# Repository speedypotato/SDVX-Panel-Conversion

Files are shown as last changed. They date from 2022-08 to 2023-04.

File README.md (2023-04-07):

# SDVX-Panel-Conversion
Turn an arcade Sound Voltex panel into a controller.

Requires a 1x2ft laser cutter, a 3d printer, and an assortment of m3 and m4 nuts and bolts.  And rubber feet.  And some more stuff.

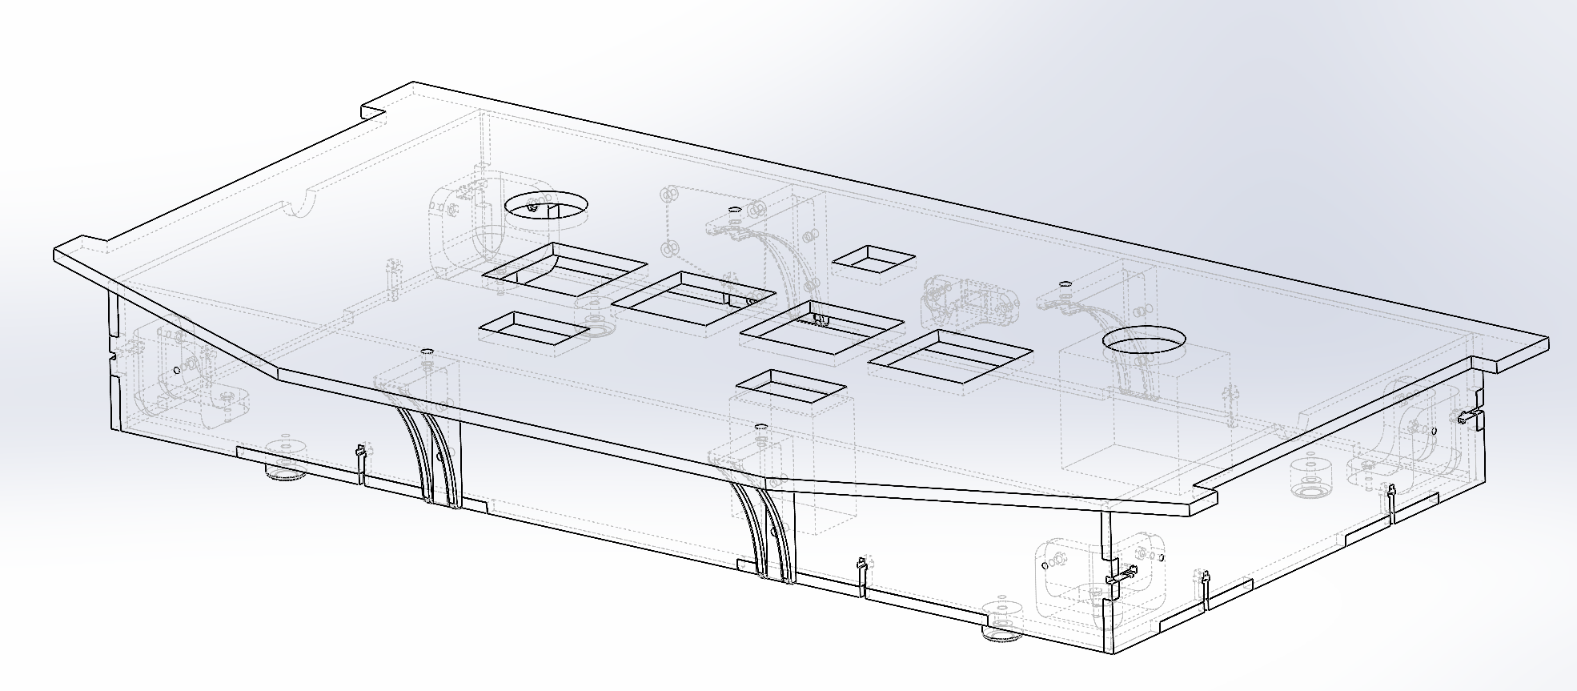
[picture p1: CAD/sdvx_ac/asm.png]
Wireframe


issues:  
- arduino holes didn't exactly line up, i just screwed in 2 screws diagonally and called it a day
- the m3x20 screws may fall out.  the corner brackets seem to do a good enough job,  can super glue m3 washers to make the m3x20 screws stay.

Note: PCB folder contains a side led rgb pcb which i was originally going to use, but the pcba turned out too expensive so I have went with the 3d printed mount instead

requires:  
- 2 1/4" 1x2ft plywood panels - mine came out to be 5.5mm..so ymmv.  Laser cut with box_dxf, units are mm
- 3d printed parts: 4 corner_bracket, 2 back_mount, 2 front_mount, 1 usb_mount, 1 arduino_leonaro_mount, 1 led_3dp, and 1 led_3dp but print mirrored
- 3m mounting tape for arduino and led sides
- m3x6 arduino
- m3x16 corner brackets
- m4x12 panel to box mount
- m3 nuts
- m4 nuts
- m3 washers
- m4 washers
- m4xsomething nuts to mount arcade panel to box
- m4 screwable rubber feet.  I got these https://www.mcmaster.com/8884T21
- top screws.  got them from a friend, they look like m4 low/slim profile of some sort.  m4x16 or something.
- ws2812b strip - i got 1m of 144leds/m because why not.

Assembly:  
- Note: I recommend doing a washer wherever a screw head touches wood or a 3d print.
- screw together box with corner pieces
- glue usb c - micro b extender into the usb holder
- screw in usb holder
- screw in front and back 3d printed mounts to box, don't forget to add nuts to all 3 points
- screw in panel
- mount arduino to plastic holder, apply 3m tape to holder.
- create wiring harness or just use dupont breadboard extenders and plug it directly into the connector using the wiring guide.  I recommend grouping all the - and COM to ground, except L/R Pot -, which get their own dedicated wire to ground
- don't forget to wire up ws2812b, needs to tap into 5v and gnd of the harness and each side has its own dedicated data line.  Cut to length, for mine i did 31 leds per side.
- assuming you've wired up arduino, plug in the micro usb adapter, peel off other side of 3m tape and mount it inside.  for me, i did it in the top left corner(looking at the top of the panel)
- string ws2812b strips through the half circle gaps to the outside of the box.
- apply mounting tape to edges of led_3dp part, then stick ws2812b strip to the mount.  Peel mounting tape and apply to panel.  Repeat for other side.
- mount feet to the bottom panel
- screw in the bottom panel

Setup https://github.com/veroxzik/arduino-konami-spoof (C:\Program Files (x86)\Arduino\hardware for me) and flash SkogaVoltex.  Might need to add arduino joystick library(just google it and import the zip).  Fastled, bounce2, and responsiveanalogread libraries can be installed through tools -> manage libraries.

This work is licensed under a Creative Commons Attribution-NonCommercial-ShareAlike 4.0 International License.

My build, including extras:  
dupont	7.3  
ws2812b	8.26  
panel	63.51  
shipping	69.5  
arduino	14.99  
usb c to micro b	1.915  
wood	8.47  
screws	15.89  
feet	3.18  
3d prints	5  
jst	0  
wire	1  
torque limiter	44  
yuan leds	11.01  
usb c cable	1  
knobs	19.98 
3m tape 5 

Total: 280.005

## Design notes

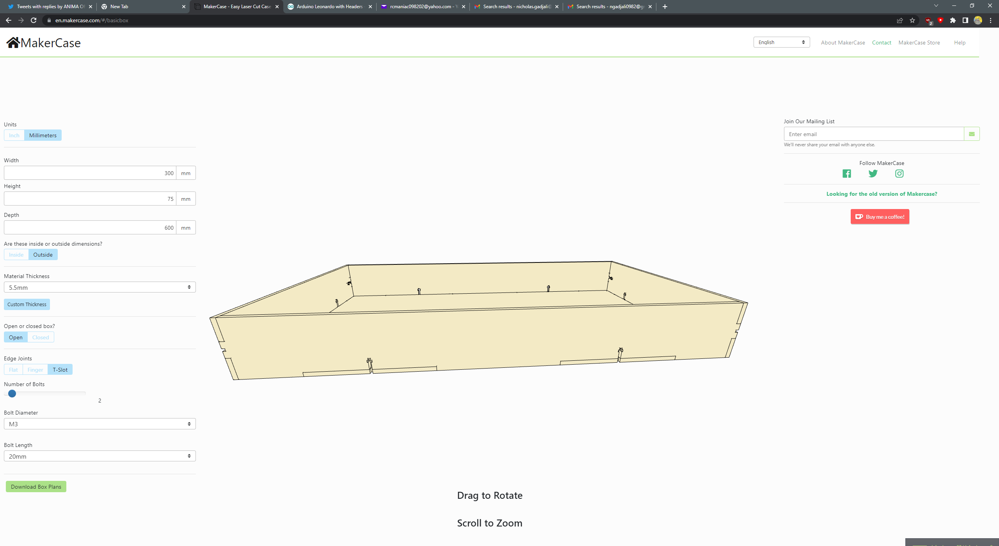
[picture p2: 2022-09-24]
CAD/sdvx_ac/box/box.png

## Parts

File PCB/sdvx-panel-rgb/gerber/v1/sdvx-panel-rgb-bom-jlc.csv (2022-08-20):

Comment | Designator | Footprint | LCSC
100nF | C1,C2,C3,C4,C5,C6,C7,C8 | Capacitor_SMD:C_0603_1608Metric_Pad1.08x0.95mm_HandSolder | C1525
s3b-xh-sm4-tb | J1,J2 | user:S3B-XH-SM4-TB | C161860
WS2812B-4020 | LED1,LED2,LED3,LED4,LED5,LED6,LED7,LED8 | agg:WS2812B-4020 | C965557

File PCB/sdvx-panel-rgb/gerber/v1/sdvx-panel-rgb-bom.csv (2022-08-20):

Source: | D:\KiCad\sdvx-panel-rgb\sdvx-panel-rgb.kicad_sch
Date: | 8/19/2022 23:46
Tool: | Eeschema (6.0.2)
Generator: | C:\Program Files\KiCad\6.0\bin\scripting\plugins/bom_csv_grouped_by_value.py
Component Count: | 20
Individual Components:
Item | Qty | Reference(s) | Value | LibPart | Footprint | Datasheet | LCSC
 |  | C1 | 100nF | Device:C_Small | Capacitor_SMD:C_0603_1608Metric_Pad1.08x0.95mm_HandSolder | ~ | C1525
 |  | C2 | 100nF | Device:C_Small | Capacitor_SMD:C_0603_1608Metric_Pad1.08x0.95mm_HandSolder | ~ | C1525
 |  | C3 | 100nF | Device:C_Small | Capacitor_SMD:C_0603_1608Metric_Pad1.08x0.95mm_HandSolder | ~ | C1525
 |  | C4 | 100nF | Device:C_Small | Capacitor_SMD:C_0603_1608Metric_Pad1.08x0.95mm_HandSolder | ~ | C1525
 |  | C5 | 100nF | Device:C_Small | Capacitor_SMD:C_0603_1608Metric_Pad1.08x0.95mm_HandSolder | ~ | C1525
 |  | C6 | 100nF | Device:C_Small | Capacitor_SMD:C_0603_1608Metric_Pad1.08x0.95mm_HandSolder | ~ | C1525
 |  | C7 | 100nF | Device:C_Small | Capacitor_SMD:C_0603_1608Metric_Pad1.08x0.95mm_HandSolder | ~ | C1525
 |  | C8 | 100nF | Device:C_Small | Capacitor_SMD:C_0603_1608Metric_Pad1.08x0.95mm_HandSolder | ~ | C1525
 |  | J1 | s3b-xh-sm4-tb | agg-kicad:CONN_01x03 | user:S3B-XH-SM4-TB |  | C161860
 |  | J2 | s3b-xh-sm4-tb | agg-kicad:CONN_01x03 | user:S3B-XH-SM4-TB |  | C161860
 |  | LED1 | WS2812B-4020 | agg-kicad:WS2812B-4020 | agg:WS2812B-4020 | https://datasheet.lcsc.com/szlcsc/2012110135_Worldsemi-WS2812B-4020_C965557.pdf | C965557
 |  | LED2 | WS2812B-4020 | agg-kicad:WS2812B-4020 | agg:WS2812B-4020 | https://datasheet.lcsc.com/szlcsc/2012110135_Worldsemi-WS2812B-4020_C965557.pdf | C965557
 |  | LED3 | WS2812B-4020 | agg-kicad:WS2812B-4020 | agg:WS2812B-4020 | https://datasheet.lcsc.com/szlcsc/2012110135_Worldsemi-WS2812B-4020_C965557.pdf | C965557
 |  | LED4 | WS2812B-4020 | agg-kicad:WS2812B-4020 | agg:WS2812B-4020 | https://datasheet.lcsc.com/szlcsc/2012110135_Worldsemi-WS2812B-4020_C965557.pdf | C965557
 |  | LED5 | WS2812B-4020 | agg-kicad:WS2812B-4020 | agg:WS2812B-4020 | https://datasheet.lcsc.com/szlcsc/2012110135_Worldsemi-WS2812B-4020_C965557.pdf | C965557
 |  | LED6 | WS2812B-4020 | agg-kicad:WS2812B-4020 | agg:WS2812B-4020 | https://datasheet.lcsc.com/szlcsc/2012110135_Worldsemi-WS2812B-4020_C965557.pdf | C965557
 |  | LED7 | WS2812B-4020 | agg-kicad:WS2812B-4020 | agg:WS2812B-4020 | https://datasheet.lcsc.com/szlcsc/2012110135_Worldsemi-WS2812B-4020_C965557.pdf | C965557
 |  | LED8 | WS2812B-4020 | agg-kicad:WS2812B-4020 | agg:WS2812B-4020 | https://datasheet.lcsc.com/szlcsc/2012110135_Worldsemi-WS2812B-4020_C965557.pdf | C965557
Collated Components:
Item | Qty | Reference(s) | Value | LibPart | Footprint | Datasheet | LCSC
1 | 8 | C1, C2, C3, C4, C5, C6, C7, C8 | 100nF | Device:C_Small | Capacitor_SMD:C_0603_1608Metric_Pad1.08x0.95mm_HandSolder | ~ | C1525
2 | 2 | J1, J2 | s3b-xh-sm4-tb | agg-kicad:CONN_01x03 | user:S3B-XH-SM4-TB |  | C161860
3 | 8 | LED1, LED2, LED3, LED4, LED5, LED6, LED7, LED8 | WS2812B-4020 | agg-kicad:WS2812B-4020 | agg:WS2812B-4020 | https://datasheet.lcsc.com/szlcsc/2012110135_Worldsemi-WS2812B-4020_C965557.pdf | C965557

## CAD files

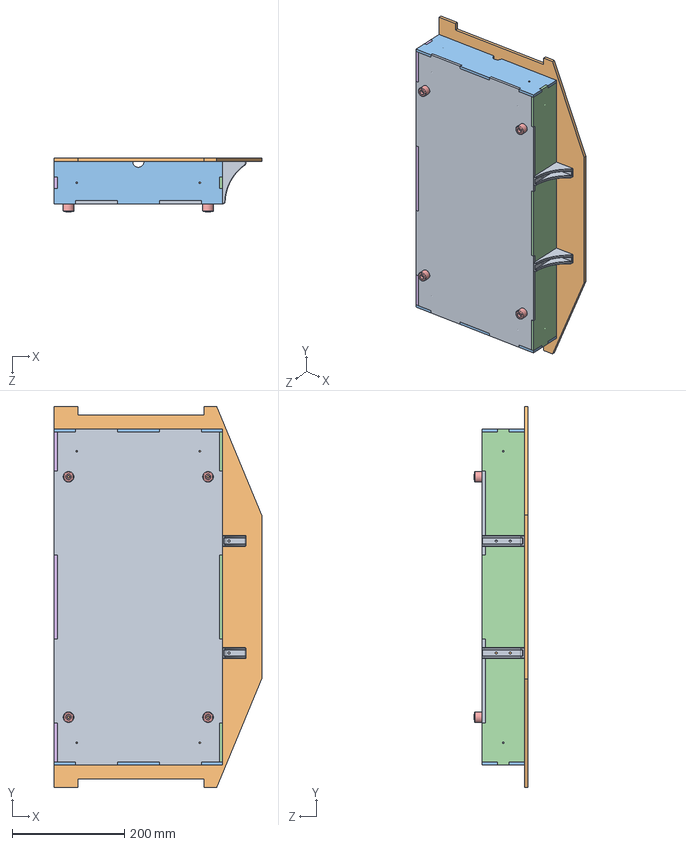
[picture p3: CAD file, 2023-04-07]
CAD/sdvx_ac/box/sdvx_ac.SLDASM
370.4 x 680.0 x 95.5 mm
bottom
panel
side x 2
front
8884T21_Heavy Duty Unthreaded Bumpers x 4
back
usb_mount
arduino_leonardo_mount
front_mount x 2
back_mount x 2
corner_bracket x 4

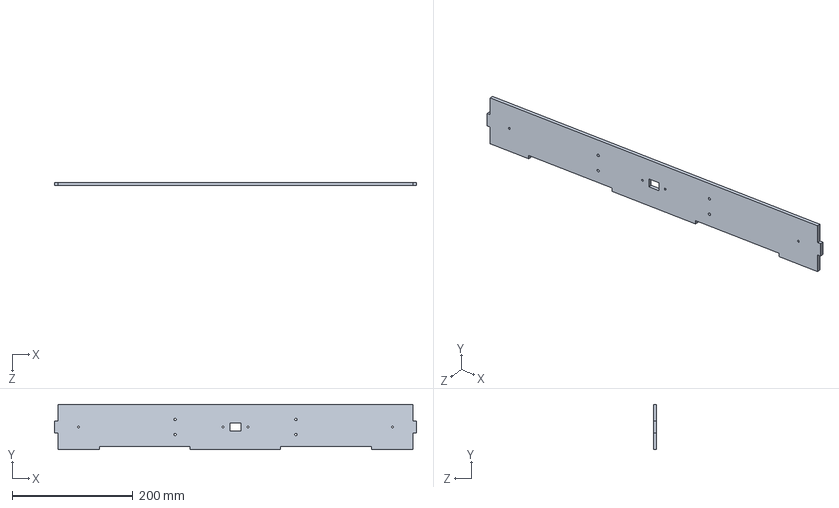
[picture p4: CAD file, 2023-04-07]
CAD/sdvx_ac/box/back.SLDPRT
600.0 x 75.0 x 5.50 mm

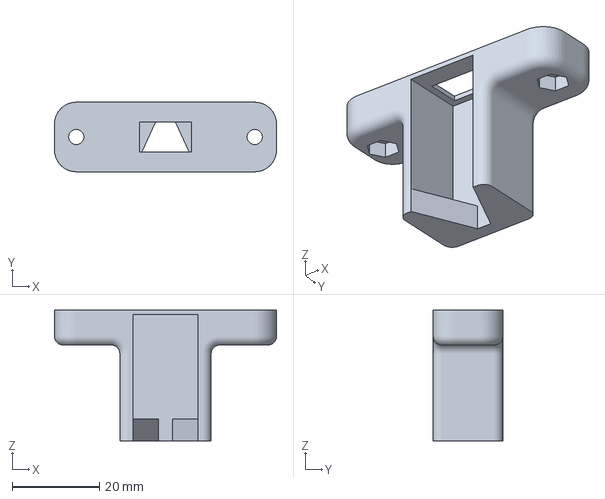
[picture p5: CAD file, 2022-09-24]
CAD/sdvx_ac/box/box_3mf/usb_mount.3MF
51.0 x 16.0 x 30.0 mm

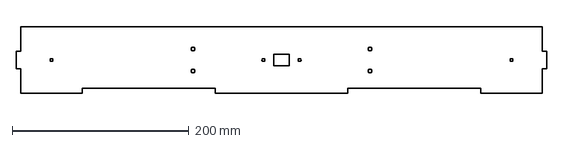
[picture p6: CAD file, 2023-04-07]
CAD/sdvx_ac/box/box_dxf/back.DXF
600.0 x 75.0 mm

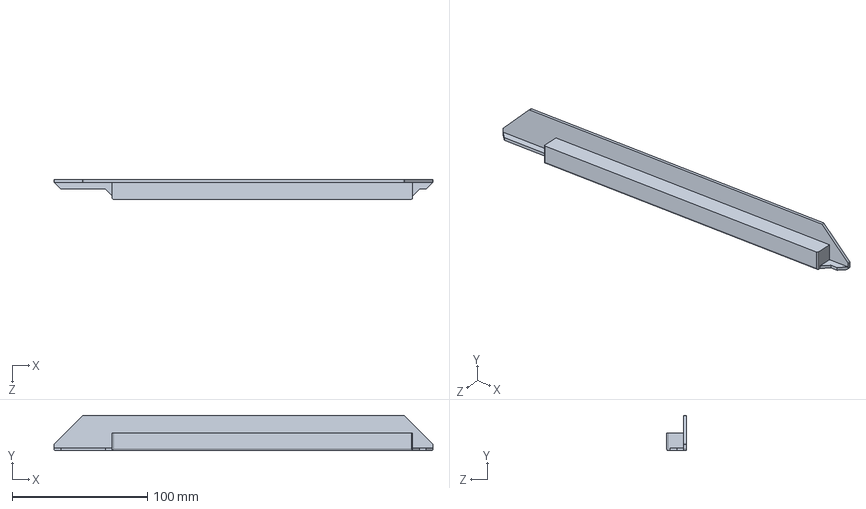
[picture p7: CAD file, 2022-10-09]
CAD/sdvx_ac/led_board_3dp/led_3dp.SLDPRT
280.0 x 26.0 x 14.5 mm

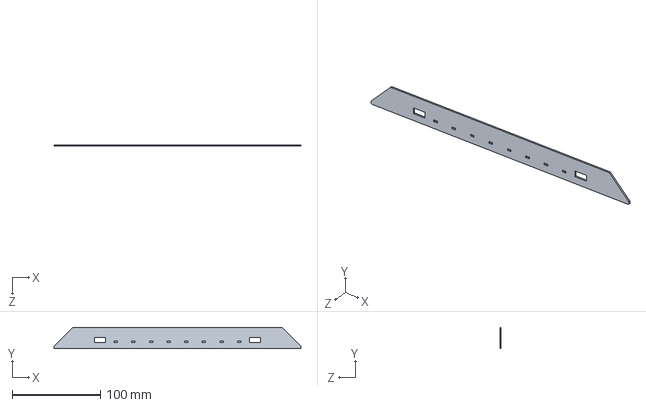
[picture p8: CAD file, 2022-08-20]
CAD/sdvx_ac/led_board_sym.SLDPRT
280.0 x 24.0 x 1.60 mm

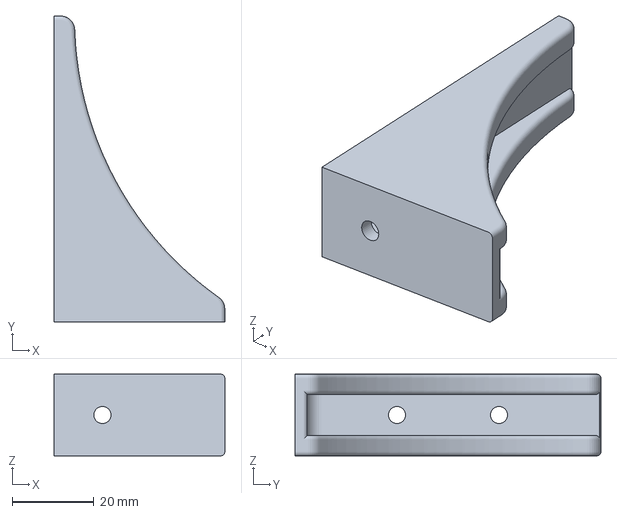
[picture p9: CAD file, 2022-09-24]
CAD/sdvx_ac/box/box_3mf/front_mount.3MF
41.8 x 75.0 x 20.0 mm

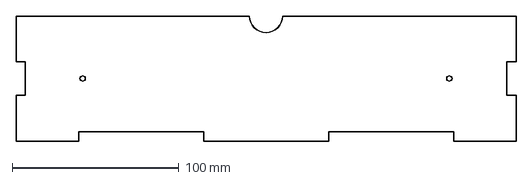
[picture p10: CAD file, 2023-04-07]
CAD/sdvx_ac/box/box_dxf/side.DXF
300.0 x 75.0 mm

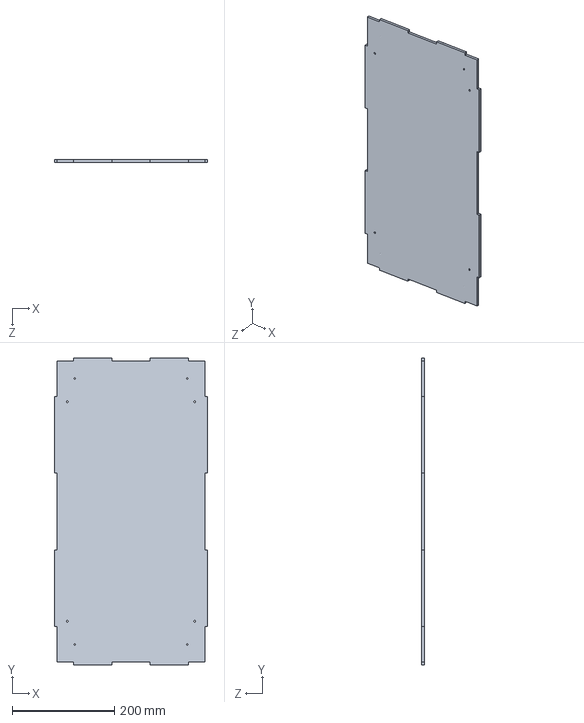
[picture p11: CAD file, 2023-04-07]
CAD/sdvx_ac/box/bottom.SLDPRT
300.0 x 600.0 x 5.50 mm

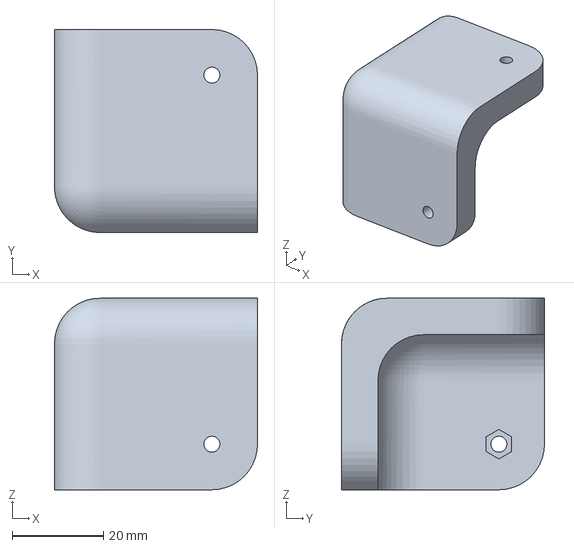
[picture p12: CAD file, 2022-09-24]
CAD/sdvx_ac/box/box_3mf/corner_bracket.3MF
44.5 x 44.5 x 42.0 mm

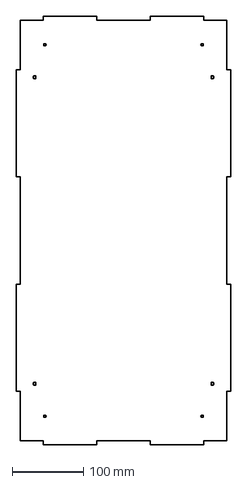
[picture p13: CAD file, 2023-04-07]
CAD/sdvx_ac/box/box_dxf/bottom.DXF
300.0 x 600.0 mm

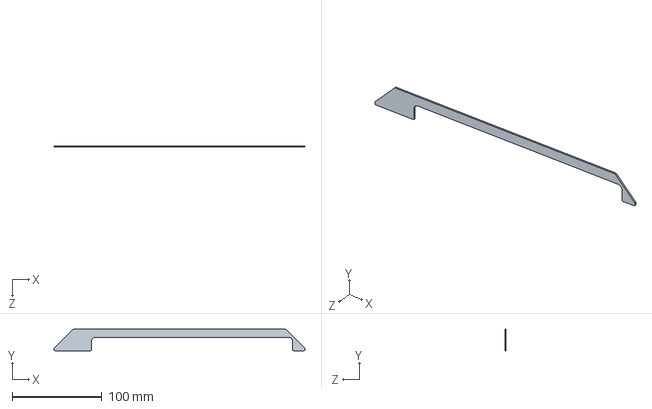
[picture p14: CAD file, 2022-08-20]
CAD/sdvx_ac/led_board.SLDPRT
280.0 x 24.0 x 1.60 mm

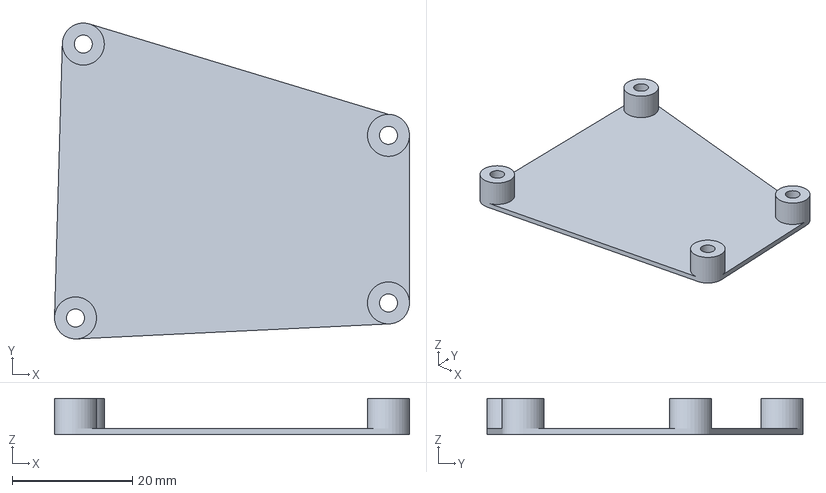
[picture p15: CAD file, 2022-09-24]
CAD/sdvx_ac/box/box_3mf/arduino_leonardo_mount.3MF
59.1 x 52.6 x 6.00 mm

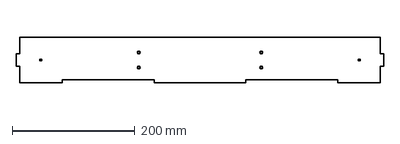
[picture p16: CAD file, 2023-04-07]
CAD/sdvx_ac/box/box_dxf/front.DXF
600.0 x 75.0 mm

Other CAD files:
CAD/sdvx_ac/box/front.SLDPRT
CAD/sdvx_ac/led_board_sym_cutout.SLDPRT
CAD/sdvx_ac/box/box_3mf/back_mount.3MF
CAD/sdvx_ac/box/side.SLDPRT
CAD/sdvx_ac/box/acrylic_panel.dxf
CAD/sdvx_ac/box/arduino_leonardo_mount.SLDPRT
CAD/sdvx_ac/box/back_mount.SLDPRT
CAD/sdvx_ac/box/box.dxf
CAD/sdvx_ac/box/corner_bracket.SLDPRT
CAD/sdvx_ac/box/front_mount.SLDPRT
CAD/sdvx_ac/box/mounting holes.SLDPRT
CAD/sdvx_ac/box/panel.SLDPRT
CAD/sdvx_ac/box/parts/8884T21_Heavy Duty Unthreaded Bumpers.SLDPRT
CAD/sdvx_ac/box/usb_mount.SLDPRT
CAD/sdvx_ac/led_board_3dp/led_3dp.3MF
CAD/sdvx_ac/led_board_sym.DXF
CAD/sdvx_ac/led_board_sym_cutout.DXF

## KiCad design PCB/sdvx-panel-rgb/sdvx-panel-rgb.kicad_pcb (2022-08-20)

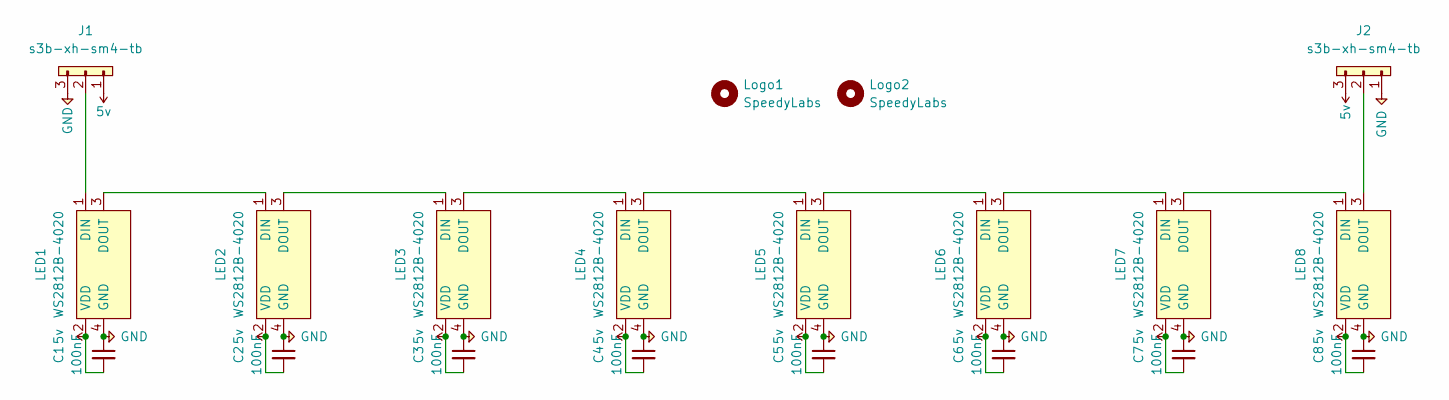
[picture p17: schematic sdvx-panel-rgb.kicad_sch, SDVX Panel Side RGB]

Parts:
C1, C2, C3, C4, C5, C6, C7, C8: 100nF; C_0603_1608Metric_Pad1.08x0.95mm_HandSolder; LCSC C1525
J1, J2: s3b-xh-sm4-tb; S3B-XH-SM4-TB; LCSC C161860
LED1, LED2, LED3, LED4, LED5, LED6, LED7, LED8: WS2812B-4020; LCSC C965557
Logo1, Logo2: SpeedyLabs; logo_small

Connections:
5v: C1.2, C2.2, C3.2, C4.2, C5.2, C6.2, C7.2, C8.2, J1.1, J2.3, LED1.2 (VDD), LED2.2 (VDD), LED3.2 (VDD), LED4.2 (VDD), LED5.2 (VDD), LED6.2 (VDD), LED7.2 (VDD), LED8.2 (VDD)
GND: C1.1, C2.1, C3.1, C4.1, C5.1, C6.1, C7.1, C8.1, J1.3, J2.1, LED1.4 (GND), LED2.4 (GND), LED3.4 (GND), LED4.4 (GND), LED5.4 (GND), LED6.4 (GND), LED7.4 (GND), LED8.4 (GND)
unnamed: J1.2, LED1.1 (DIN)
unnamed: LED1.3 (DOUT), LED2.1 (DIN)
unnamed: LED2.3 (DOUT), LED3.1 (DIN)
unnamed: LED3.3 (DOUT), LED4.1 (DIN)
unnamed: LED4.3 (DOUT), LED5.1 (DIN)
unnamed: LED5.3 (DOUT), LED6.1 (DIN)
unnamed: LED6.3 (DOUT), LED7.1 (DIN)
unnamed: LED7.3 (DOUT), LED8.1 (DIN)
unnamed: J2.2, LED8.3 (DOUT)

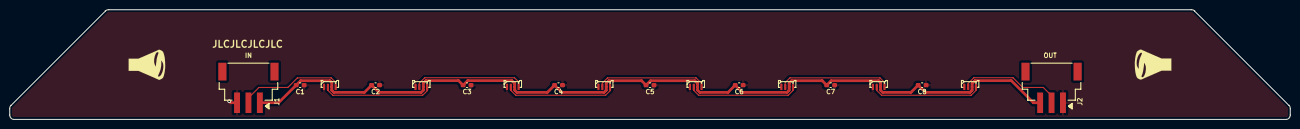
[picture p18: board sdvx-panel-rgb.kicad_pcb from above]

Board: 2 copper layers, 280.0 x 24.0 mm, 20 parts (0 on the bottom side), 11 nets.

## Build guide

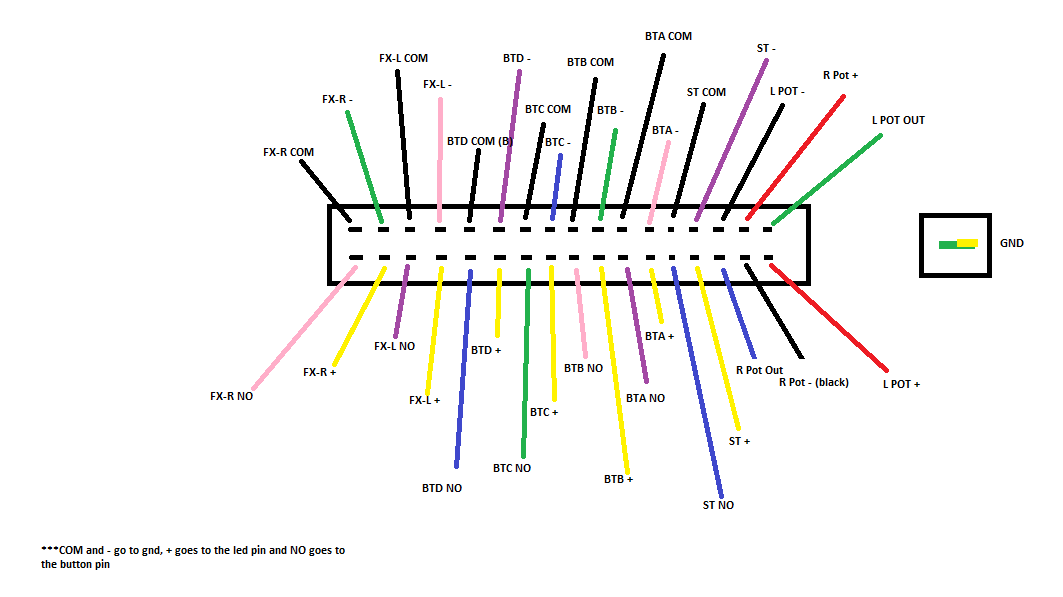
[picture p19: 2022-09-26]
SDVX_Wiring_Guide_Arcade_Panel.png

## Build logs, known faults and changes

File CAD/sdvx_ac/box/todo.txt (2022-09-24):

-box needs holes for mounting hole l brackets
-usb cutout/mount
-arduino mount

maybe rgb strip + 3d printed enclosure

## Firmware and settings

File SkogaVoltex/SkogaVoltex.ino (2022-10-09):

/**
 * Originally written by Skogaby
 * Modified by SpeedyPotato
 */

#define cbi(sfr, bit) (_SFR_BYTE(sfr) &= ~_BV(bit))
#define sbi(sfr, bit) (_SFR_BYTE(sfr) |= _BV(bit))

#include <Bounce2.h>
#include <FastLED.h>
#include <Joystick.h>
#include <ResponsiveAnalogRead.h>
#include "PluggableUSB.h"
#include "HID.h"

// Pin setup
#define ADC_MAX 1024
#define NUM_BUTTONS 9
#define NUM_KNOBS 2
#define NUM_LED_STRIPS 2
#define NUM_LEDS_PER_STRIP 31
#define LED_TYPE WS2812B
#define LED_ORDER GRB

// HID lighting setup
#define NUMBER_OF_SINGLE 7
#define NUMBER_OF_RGB 1

bool lightStates[NUMBER_OF_SINGLE] = { false };
unsigned long lightTimestamp = 0;

typedef struct {
  uint8_t brightness;
} SingleLED;

typedef struct {
  uint8_t r;
  uint8_t g;
  uint8_t b;
} RGBLed;

// Main output
Joystick_ Joystick(JOYSTICK_DEFAULT_REPORT_ID, JOYSTICK_TYPE_GAMEPAD, NUM_BUTTONS, 0,
 true, true, false, false, false, false, false, false, false, false, false);

// Button pins
const byte buttonLightPins[NUM_BUTTONS] = { 0, 1, 2, 3, 4, 5, 19, 19, 6 };
const byte buttonInputPins[NUM_BUTTONS] = { 7, 8, 9, 10, 11, 12, 20, 20, 13 };
const byte knobPin1 = A0;
const byte knobPin2 = A1;
const byte ledPin1 = A2;
const byte ledPin2 = A3;
CRGB leds[NUM_LED_STRIPS][NUM_LEDS_PER_STRIP];

// Button debounce objects
const Bounce buttons[NUM_BUTTONS] = {
  Bounce(),
  Bounce(),
  Bounce(),
  Bounce(),
  Bounce(),
  Bounce(),
  Bounce(),
  Bounce(),
  Bounce()
};

// Objects to read the analog values of the knobs responsively, but with smoothing
ResponsiveAnalogRead leftKnob(knobPin1, true);
ResponsiveAnalogRead rightKnob(knobPin2, true);

void setAllLeds(CRGB color);

/**
 * Setup all the hardware pins, etc.
 */
void setup() {
  //Serial.begin(115200);
  //while (!Serial) { delay(10); }
  
  // Setup the ADC registers to run more quickly
  sbi(ADCSRA, ADPS2);
  cbi(ADCSRA, ADPS1);
  cbi(ADCSRA, ADPS0);

  // Joystick init
  Joystick.begin(false);
  Joystick.setXAxisRange(0, ADC_MAX);
  Joystick.setYAxisRange(0, ADC_MAX);

  // Initialize the IO pins
  for (int i = 0; i < NUM_BUTTONS; i++) {
    if (buttonInputPins[i] == 20) continue;
    pinMode(buttonLightPins[i], OUTPUT);
    buttons[i].attach(buttonInputPins[i], INPUT_PULLUP);
    buttons[i].interval(5);
  }

  pinMode(knobPin1, INPUT);
  pinMode(knobPin2, INPUT);

  // Initialize the LED strips
  FastLED.addLeds<LED_TYPE, ledPin1, LED_ORDER>(leds[0], NUM_LEDS_PER_STRIP);
  FastLED.addLeds<LED_TYPE, ledPin2, LED_ORDER>(leds[1], NUM_LEDS_PER_STRIP);

  // Boot LED sequence
  FastLED.setBrightness(128);
  setAllLeds(CRGB::Blue);
  FastLED.show();
}

/**
 * Callback for HID lighting events.
 */
void light_update(SingleLED* single_leds, RGBLed* rgb_leds) {
  // Read the on/off non-RGB lights
  for(int i = 0; i < NUMBER_OF_SINGLE; i++) {
    bool isOn = single_leds[i].brightness > 128;
    lightStates[i] = isOn;
  }

  // Read the RGB lights
  CRGB color = CRGB(rgb_leds[0].r, rgb_leds[0].g, rgb_leds[0].b);
  setAllLeds(color);
  lightTimestamp = millis();
}

/**
 * Main runtime loop.
 */
void loop() {
  // Read the button states
  for (int i = 0; i < NUM_BUTTONS; i++) {
    if (buttonInputPins[i] == 20) continue;
    buttons[i].update();
    Joystick.setButton(i, !buttons[i].read());
  }

  // Read the knobs
  leftKnob.update();
  rightKnob.update();

  // Output the joystick states
  Joystick.setXAxis(leftKnob.getValue());
  Joystick.setYAxis(rightKnob.getValue());
  Joystick.sendState();
  
  if (lightTimestamp + 1000 < millis()) {
    // Update the lights as reactive
    for (int i = 0; i < NUMBER_OF_SINGLE - 1; i++) {
      digitalWrite(buttonLightPins[i], !buttons[i].read());
    }
    digitalWrite(buttonLightPins[NUM_BUTTONS - 1], !buttons[NUM_BUTTONS - 1].read());
  } else {
    // Update the lights as necessary
    for (int i = 0; i < NUMBER_OF_SINGLE - 1; i++) {
      digitalWrite(buttonLightPins[i], lightStates[i]);
    }
    digitalWrite(buttonLightPins[NUM_BUTTONS - 1], lightStates[NUMBER_OF_SINGLE - 1]);
  }
  FastLED.show();
}

/**
 * Helper function to set all the LEDs across both strips the same color.
 */
void setAllLeds(CRGB color) {
  for (int strip = 0; strip < NUM_LED_STRIPS; strip++) {
    for (int led = 0; led < NUM_LEDS_PER_STRIP; led++) {
      leds[strip][led] = color;
    }
  }
}

// ******************************
// don't need to edit below here

#define NUMBER_OF_LIGHTS (NUMBER_OF_SINGLE + NUMBER_OF_RGB*3)
#if NUMBER_OF_LIGHTS > 63
  #error You must have less than 64 lights
#endif

union {
  struct {
    SingleLED singles[NUMBER_OF_SINGLE];
    RGBLed rgb[NUMBER_OF_RGB];
  } leds;
  uint8_t raw[NUMBER_OF_LIGHTS];
} led_data;

static const uint8_t PROGMEM _hidReportLEDs[] = {
    0x05, 0x01,                    // USAGE_PAGE (Generic Desktop)
    0x09, 0x00,                    // USAGE (Undefined)
    0xa1, 0x01,                    // COLLECTION (Application)
    // Globals
    0x95, NUMBER_OF_LIGHTS,        //   REPORT_COUNT
    0x75, 0x08,                    //   REPORT_SIZE (8)
    0x15, 0x00,                    //   LOGICAL_MINIMUM (0)
    0x26, 0xff, 0x00,              //   LOGICAL_MAXIMUM (255)
    0x05, 0x0a,                    //   USAGE_PAGE (Ordinals)
    // Locals
    0x19, 0x01,                    //   USAGE_MINIMUM (Instance 1)
    0x29, NUMBER_OF_LIGHTS,        //   USAGE_MAXIMUM (Instance n)
    0x91, 0x02,                    //   OUTPUT (Data,Var,Abs)
    // BTools needs at least 1 input to work properly
    0x19, 0x01,                    //   USAGE_MINIMUM (Instance 1)
    0x29, 0x01,                    //   USAGE_MAXIMUM (Instance 1)
    0x81, 0x03,                    //   INPUT (Cnst,Var,Abs)
    0xc0                           // END_COLLECTION
};

// This is almost entirely copied from NicoHood's wonderful RawHID example
// Trimmed to the bare minimum
// https://github.com/NicoHood/HID/blob/master/src/SingleReport/RawHID.cpp
class HIDLED_ : public PluggableUSBModule {

  uint8_t epType[1];
  
  public:
    HIDLED_(void) : PluggableUSBModule(1, 1, epType) {
      epType[0] = EP_TYPE_INTERRUPT_IN;
      PluggableUSB().plug(this);
    }

    int getInterface(uint8_t* interfaceCount) {
      *interfaceCount += 1; // uses 1
      HIDDescriptor hidInterface = {
        D_INTERFACE(pluggedInterface, 1, USB_DEVICE_CLASS_HUMAN_INTERFACE, HID_SUBCLASS_NONE, HID_PROTOCOL_NONE),
        D_HIDREPORT(sizeof(_hidReportLEDs)),
        D_ENDPOINT(USB_ENDPOINT_IN(pluggedEndpoint), USB_ENDPOINT_TYPE_INTERRUPT, USB_EP_SIZE, 16)
      };
      return USB_SendControl(0, &hidInterface, sizeof(hidInterface));
    }
    
    int getDescriptor(USBSetup& setup)
    {
      // Check if this is a HID Class Descriptor request
      if (setup.bmRequestType != REQUEST_DEVICETOHOST_STANDARD_INTERFACE) { return 0; }
      if (setup.wValueH != HID_REPORT_DESCRIPTOR_TYPE) { return 0; }
    
      // In a HID Class Descriptor wIndex contains the interface number
      if (setup.wIndex != pluggedInterface) { return 0; }
    
      return USB_SendControl(TRANSFER_PGM, _hidReportLEDs, sizeof(_hidReportLEDs));
    }
    
    bool setup(USBSetup& setup)
    {
      if (pluggedInterface != setup.wIndex) {
        return false;
      }
    
      uint8_t request = setup.bRequest;
      uint8_t requestType = setup.bmRequestType;
    
      if (requestType == REQUEST_DEVICETOHOST_CLASS_INTERFACE)
      {
        return true;
      }
    
      if (requestType == REQUEST_HOSTTODEVICE_CLASS_INTERFACE) {
        if (request == HID_SET_REPORT) {
          if(setup.wValueH == HID_REPORT_TYPE_OUTPUT && setup.wLength == NUMBER_OF_LIGHTS){
            USB_RecvControl(led_data.raw, NUMBER_OF_LIGHTS);
            light_update(led_data.leds.singles, led_data.leds.rgb);
            return true;
          }
        }
      }
    
      return false;
    }
};

HIDLED_ HIDLeds;

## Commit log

2022-08-20 Initial upload, v1 RGB PCB
    [acrylic_panel.dxf, led_board.SLDPRT, led_board_sym.DXF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]
2022-09-24 v1, everything but rgb strip support
    [8884T21_Heavy Duty Unthreaded Bumpers.SLDPRT, acrylic_panel.dxf, arduino_leonardo_mount.SLDPRT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]
2022-09-24 added internal corner brackets in case edge ones aren't good enough
    [arduino_leonardo_mount.3MF, back.DXF, back.SLDPRT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]
2022-09-26 added screws, wiring, and firmware (thanks skogaby)
2022-10-09 Finished build
    [led_3dp.3MF, led_3dp.SLDPRT]
2023-04-07 Removed side screw points
    [back.DXF, back.SLDPRT, bottom.DXF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]
